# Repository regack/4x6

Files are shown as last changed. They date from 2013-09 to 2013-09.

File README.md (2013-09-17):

4x6
===

4x6 Keypad
v0.1
Based on GH60 Rev B

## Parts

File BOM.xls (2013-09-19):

ref | value | datasheet | footprint | Field1 | Field2 | Field3 | Field4 | Field5 | Field6 | Field7
C1 | 22p | http://www.tme.eu/pl/Document/7da762c1dbaf553c64ad9c40d3603826/mlcc_samsung.pdf |  | http://www.tme.eu/pl/Document/7da762c1dbaf553c64ad9c40d3603826/mlcc_samsung.pdf | Samsung | CL21C220JBANNNC | TME | CL21C220JBANNNC
C2 | 22p | http://www.tme.eu/pl/Document/7da762c1dbaf553c64ad9c40d3603826/mlcc_samsung.pdf |  | http://www.tme.eu/pl/Document/7da762c1dbaf553c64ad9c40d3603826/mlcc_samsung.pdf | Samsung | CL21C220JBANNNC | TME | CL21C220JBANNNC
C3 | 1u | http://www.jm.pl/karty/CCCX7R.pdf |  | http://www.jm.pl/karty/CCCX7R.pdf | Samsung | CL21B105KAFNNNE | TME | CL21B105KAFNNNE
C4 | 100n | http://www.tme.eu/pl/Document/7da762c1dbaf553c64ad9c40d3603826/mlcc_samsung.pdf |  | http://www.tme.eu/pl/Document/7da762c1dbaf553c64ad9c40d3603826/mlcc_samsung.pdf | Samsung | CL21B104KBCNNNC | TME | CL21B104KBCNNNC
C5 | 100n | http://www.tme.eu/pl/Document/7da762c1dbaf553c64ad9c40d3603826/mlcc_samsung.pdf |  | http://www.tme.eu/pl/Document/7da762c1dbaf553c64ad9c40d3603826/mlcc_samsung.pdf | Samsung | CL21B104KBCNNNC | TME | CL21B104KBCNNNC
C6 | 100n | http://www.tme.eu/pl/Document/7da762c1dbaf553c64ad9c40d3603826/mlcc_samsung.pdf |  | http://www.tme.eu/pl/Document/7da762c1dbaf553c64ad9c40d3603826/mlcc_samsung.pdf | Samsung | CL21B104KBCNNNC | TME | CL21B104KBCNNNC
C7 | 100n | http://www.tme.eu/pl/Document/7da762c1dbaf553c64ad9c40d3603826/mlcc_samsung.pdf |  | http://www.tme.eu/pl/Document/7da762c1dbaf553c64ad9c40d3603826/mlcc_samsung.pdf | Samsung | CL21B104KBCNNNC | TME | CL21B104KBCNNNC
C8 | 1u | http://www.tme.eu/pl/Document/7da762c1dbaf553c64ad9c40d3603826/mlcc_samsung.pdf |  | http://www.tme.eu/pl/Document/7da762c1dbaf553c64ad9c40d3603826/mlcc_samsung.pdf | Samsung | CL21B104KBCNNNC | TME | CL21B104KBCNNNC
D1 | 1N4148 |  |  |  | DC Components | CD4148WS(0805C) | TME | 1N4148-0805
D2 | 1N4148 |  |  |  | DC Components | CD4148WS(0805C) | TME | 1N4148-0805
D3 | 1N4148 |  |  |  | DC Components | CD4148WS(0805C) | TME | 1N4148-0805
D4 | 1N4148 |  |  |  | DC Components | CD4148WS(0805C) | TME | 1N4148-0805
D5 | 1N4148 |  |  |  | DC Components | CD4148WS(0805C) | TME | 1N4148-0805
D6 | 1N4148 |  |  |  | DC Components | CD4148WS(0805C) | TME | 1N4148-0805
D7 | 1N4148 |  |  |  | DC Components | CD4148WS(0805C) | TME | 1N4148-0805
D8 | 1N4148 |  |  |  | DC Components | CD4148WS(0805C) | TME | 1N4148-0805
D9 | 1N4148 |  |  |  | DC Components | CD4148WS(0805C) | TME | 1N4148-0805
D10 | 1N4148 |  |  |  | DC Components | CD4148WS(0805C) | TME | 1N4148-0805
D11 | 1N4148 |  |  |  | DC Components | CD4148WS(0805C) | TME | 1N4148-0805
D12 | 1N4148 |  |  |  | DC Components | CD4148WS(0805C) | TME | 1N4148-0805
D13 | 1N4148 |  |  |  | DC Components | CD4148WS(0805C) | TME | 1N4148-0805
D14 | 1N4148 |  |  |  | DC Components | CD4148WS(0805C) | TME | 1N4148-0805
D15 | 1N4148 |  |  |  | DC Components | CD4148WS(0805C) | TME | 1N4148-0805
D16 | 1N4148 |  |  |  | DC Components | CD4148WS(0805C) | TME | 1N4148-0805
D17 | 1N4148 |  |  |  | DC Components | CD4148WS(0805C) | TME | 1N4148-0805
D18 | 1N4148 |  |  |  | DC Components | CD4148WS(0805C) | TME | 1N4148-0805
D19 | 1N4148 |  |  |  | DC Components | CD4148WS(0805C) | TME | 1N4148-0805
D20 | 1N4148 |  |  |  | DC Components | CD4148WS(0805C) | TME | 1N4148-0805
D21 | 1N4148 |  |  |  | DC Components | CD4148WS(0805C) | TME | 1N4148-0805
D22 | 1N4148 |  |  |  | DC Components | CD4148WS(0805C) | TME | 1N4148-0805
D23 | 1N4148 |  |  |  | DC Components | CD4148WS(0805C) | TME | 1N4148-0805
D24 | 1N4148 |  |  |  | DC Components | CD4148WS(0805C) | TME | 1N4148-0805
DC1 | LED
DF1 | LED
DF2 | LED
DF3 | LED
IC1 | ATMEGA32U4 | http://www.atmel.com/dyn/resources/prod_documents/doc7766.pdf | TQFP44 | http://www.atmel.com/dyn/resources/prod_documents/doc7766.pdf | Atmel | ATmega32U4-AU | DigiKey | ATMEGA32U4-AU-ND
J1 | MINI | http://www.tme.eu/pl/Document/af7e127923dc7f74ac659db082bbc882/mx54819.pdf |  | http://www.tme.eu/pl/Document/af7e127923dc7f74ac659db082bbc882/mx54819.pdf | Natconn | U24-05XXX-1 | Alibaba
P1 | MISO
P2 | Vcc
P3 | SCK
P4 | MOSI
P5 | RES
P6 | GND
P200 | GND
P201 | GND
P202 | GND
P203 | GND
P204 | GND
P205 | GND
R1 | 22 | http://www.tme.eu/pl/Document/e5152f6c2c4f933b61676f6de7ae79a8/dcrcw.pdf |  | http://www.tme.eu/pl/Document/e5152f6c2c4f933b61676f6de7ae79a8/dcrcw.pdf | Vishay | CRCW080522R0JNTABC | TME | CRCW080522R0JNTABC
R2 | 22 | http://www.tme.eu/pl/Document/e5152f6c2c4f933b61676f6de7ae79a8/dcrcw.pdf |  | http://www.tme.eu/pl/Document/e5152f6c2c4f933b61676f6de7ae79a8/dcrcw.pdf | Vishay | CRCW080522R0JNTABC | TME | CRCW080522R0JNTABC
R3 | 10k | http://www.tme.eu/pl/Document/e5152f6c2c4f933b61676f6de7ae79a8/dcrcw.pdf |  | http://www.tme.eu/pl/Document/e5152f6c2c4f933b61676f6de7ae79a8/dcrcw.pdf | Vishay | CRCW080510K0JNTABC | TME | CRCW080510K0JNTABC
R4 | 300
R5 | 10k | http://www.tme.eu/pl/Document/e5152f6c2c4f933b61676f6de7ae79a8/dcrcw.pdf |  | http://www.tme.eu/pl/Document/e5152f6c2c4f933b61676f6de7ae79a8/dcrcw.pdf | Vishay | CRCW080510K0JNTABC | TME | CRCW080510K0JNTABC
RF1 | R
RF2 | R
RF3 | R
S0 | DTSM-6 | http://www.jm.pl/karty/DTSJW.pdf | switch-tact-DTSM-6 | http://www.jm.pl/karty/DTSJW.pdf | Ninigi | TACTB-64K-F | TME | TACTB-64K-F
S1 | MX1A
S2 | MX1A
S3 | MX1A
S4 | MX1A
S5 | MX1A
S6 | MX1A
S7 | MX1A
S8 | MX1A
S9 | MX1A
S10 | MX1A
S11 | MX1A
S12 | MX1A
S13 | MX1A
S14 | MX1A
S15 | MX1A
S16 | MX1A
S17 | MX1A
S18 | MX1A
S19 | MX1A
S20 | MX1A
S21 | MX1A
S22 | MX1A
S23 | MX1A
S24 | MX1A
S51 | MX1A
S171 | MX1A
S181 | MX1A
S191 | MX1A
S201 | MX1A
S211 | MX1A
X1 | ASX3F |  |  |  | YIC | 16.00M-SMDXT324 | TME | 16.00M-SMDXT324

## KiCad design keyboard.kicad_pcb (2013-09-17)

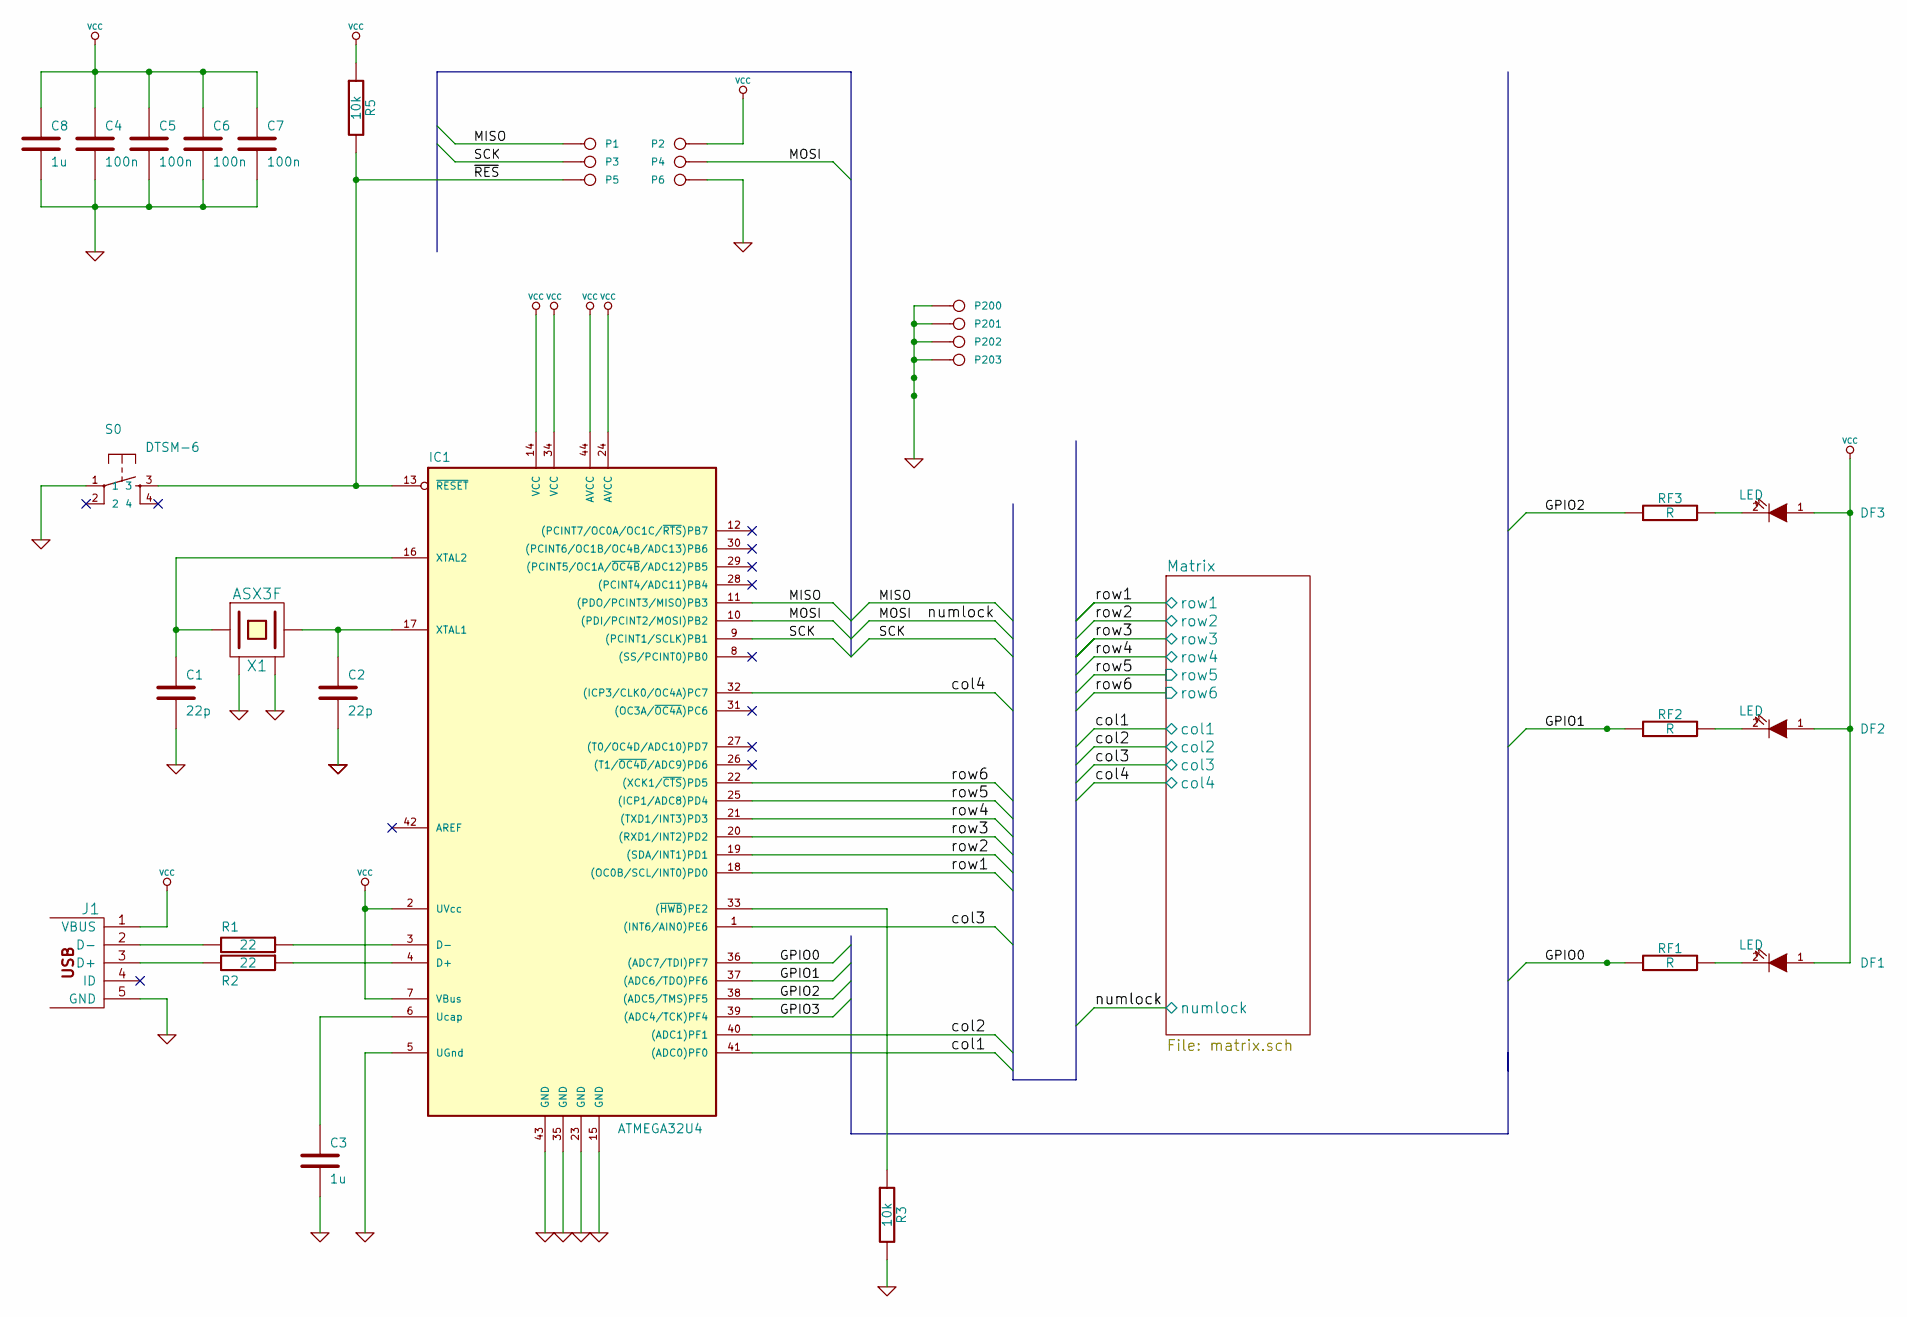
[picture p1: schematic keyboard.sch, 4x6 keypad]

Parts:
C1, C2: 22p
C3, C8: 1u
C4, C5, C6, C7: 100n
DF1, DF2, DF3: LED
IC1: ATMEGA32U4; TQFP44
J1: MINI
P1: MISO
P2: Vcc
P3: SCK
P4: MOSI
P5: RES
P6, P200, P201, P202, P203: GND
R1, R2: 22
R3, R5: 10k
RF1, RF2, RF3: R
S0: DTSM-6; switch-tact-DTSM-6
X1: ASX3F

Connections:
/GPIO0: IC1.36 ((ADC7/TDI)PF7), RF1.1
/GPIO1: IC1.37 ((ADC6/TDO)PF6), RF2.1
/GPIO2: IC1.38 ((ADC5/TMS)PF5), RF3.1
/MISO: IC1.11 ((PDO/PCINT3/MISO)PB3), P1.1
/Matrix/col1: IC1.41 ((ADC0)PF0); also elsewhere on the board
/Matrix/col2: IC1.40 ((ADC1)PF1); also elsewhere on the board
/Matrix/col3: IC1.1 ((INT6/AIN0)PE6); also elsewhere on the board
/Matrix/col4: IC1.32 ((ICP3/CLK0/OC4A)PC7); also elsewhere on the board
/Matrix/numlock: IC1.10 ((PDI/PCINT2/MOSI)PB2), P4.1; also elsewhere on the board
/Matrix/row1: IC1.18 ((OC0B/SCL/INT0)PD0); also elsewhere on the board
/Matrix/row2: IC1.19 ((SDA/INT1)PD1); also elsewhere on the board
/Matrix/row3: IC1.20 ((RXD1/INT2)PD2); also elsewhere on the board
/Matrix/row4: IC1.21 ((TXD1/INT3)PD3); also elsewhere on the board
/Matrix/row5: IC1.25 ((ICP1/ADC8)PD4); also elsewhere on the board
/Matrix/row6: IC1.22 ((XCK1/~CTS~)PD5); also elsewhere on the board
/SCK: IC1.9 ((PCINT1/SCLK)PB1), P3.1
/~RES~: IC1.13 (~RESET~), P5.1, R5.2, S0.3
GND: C1.2, C2.2, C3.2, C4.2, C5.2, C6.2, C7.2, C8.2, IC1.5 (UGnd), IC1.15 (GND), IC1.23 (GND), IC1.35 (GND), IC1.43 (GND), J1.5 (GND), P6.1, P200.1, P201.1, P202.1, P203.1, R3.2, S0.1, X1.2 (GND), X1.4 (GND)
unnamed: C1.1, IC1.16 (XTAL2), X1.1
unnamed: C2.1, IC1.17 (XTAL1), X1.3 (2)
unnamed: J1.2 (D-), R1.2
unnamed: J1.3 (D+), R2.2
unnamed: IC1.3 (D-), R1.1
unnamed: C3.1, IC1.6 (Ucap)
unnamed: IC1.4 (D+), R2.1
unnamed: IC1.33 ((~HWB~)PE2), R3.1
unnamed: DF3.2 (K), RF3.2
unnamed: DF1.2 (K), RF1.2
unnamed: DF2.2 (K), RF2.2
VCC: C4.1, C5.1, C6.1, C7.1, C8.1, DF1.1 (A), DF2.1 (A), DF3.1 (A), IC1.2 (UVcc), IC1.7 (VBus), IC1.14 (VCC), IC1.24 (AVCC), IC1.34 (VCC), IC1.44 (AVCC), J1.1 (VBUS), P2.1, R5.1; also elsewhere on the board

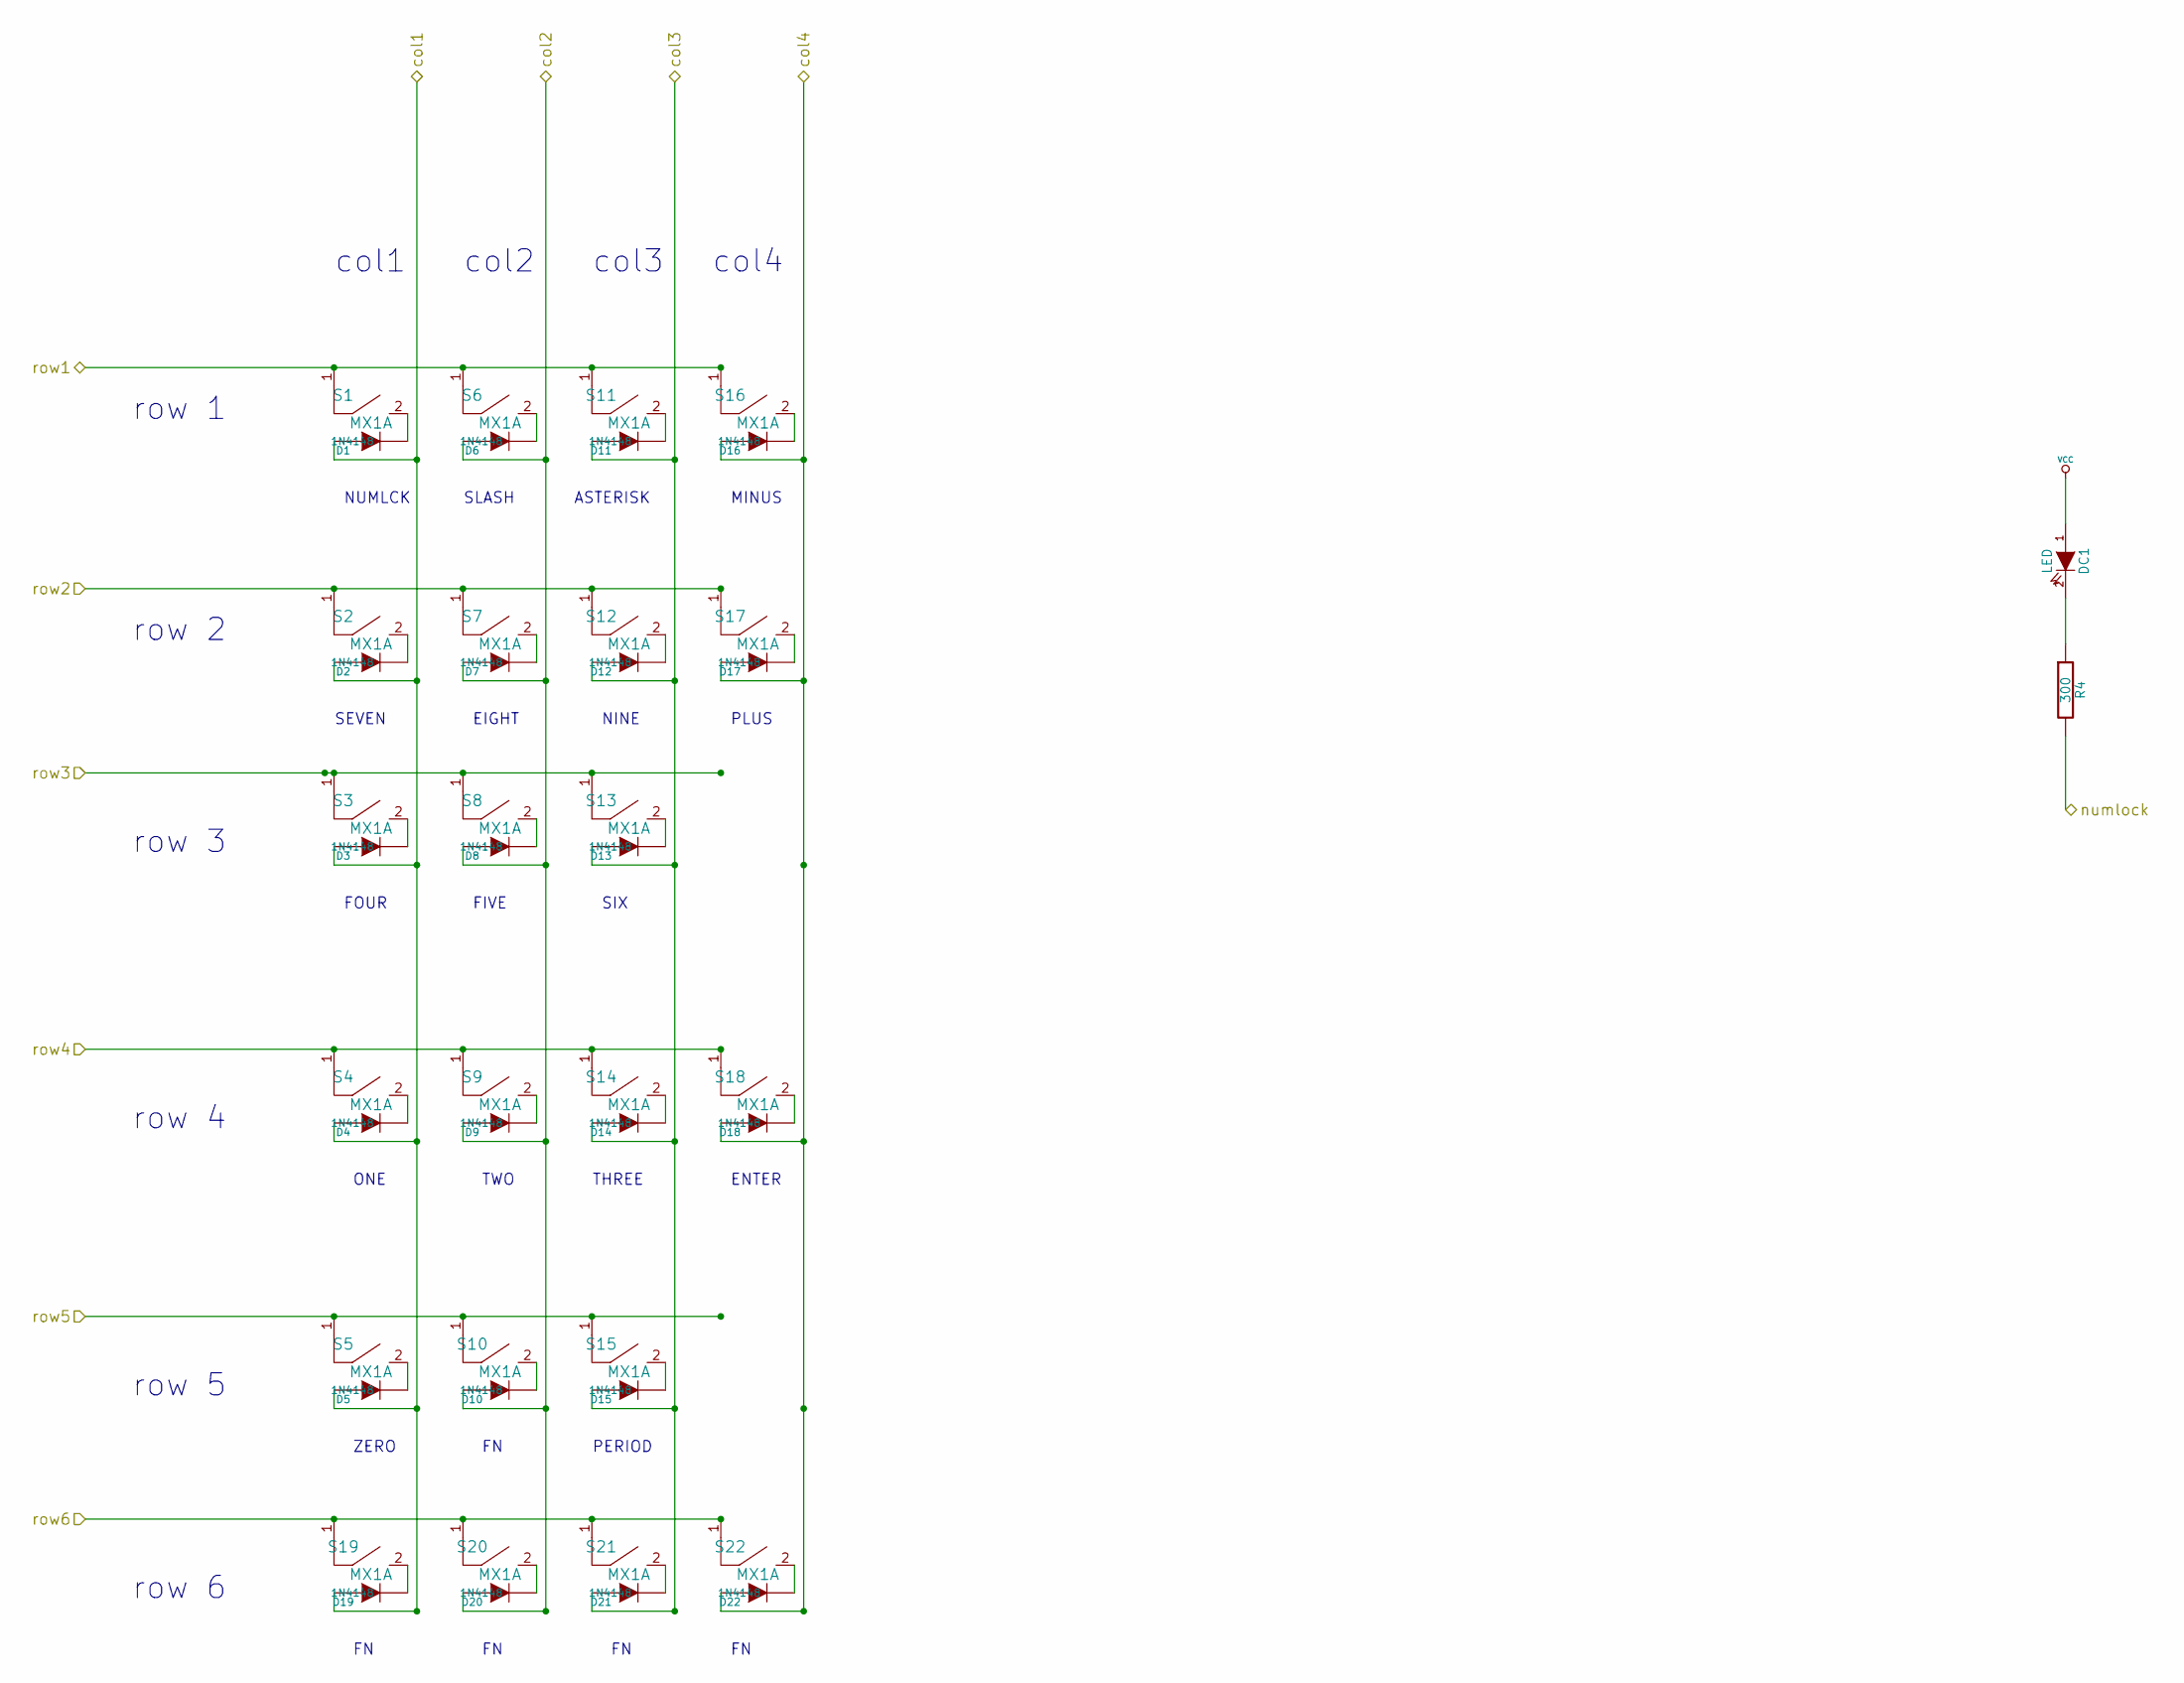
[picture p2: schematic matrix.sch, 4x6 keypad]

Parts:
D1, D2, D3, D4, D5, D6, D7, D8, D9, D10, D11, D12, D13, D14, D15, D16, D17, D18, D19, D20, D21, D22: 1N4148
DC1: LED
R4: 300
S1, S2, S3, S4, S5, S6, S7, S8, S9, S10, S11, S12, S13, S14, S15, S16, S17, S18, S19, S20, S21, S22: MX1A

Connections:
/Matrix/col1: D1.1 (A), D2.1 (A), D3.1 (A), D4.1 (A), D5.1 (A), D19.1 (A); also elsewhere on the board
/Matrix/col2: D6.1 (A), D7.1 (A), D8.1 (A), D9.1 (A), D10.1 (A), D20.1 (A); also elsewhere on the board
/Matrix/col3: D11.1 (A), D12.1 (A), D13.1 (A), D14.1 (A), D15.1 (A), D21.1 (A); also elsewhere on the board
/Matrix/col4: D16.1 (A), D17.1 (A), D18.1 (A), D22.1 (A); also elsewhere on the board
/Matrix/numlock: R4.2; also elsewhere on the board
/Matrix/row1: S1.1, S6.1, S11.1, S16.1; also elsewhere on the board
/Matrix/row2: S2.1, S7.1, S12.1, S17.1; also elsewhere on the board
/Matrix/row3: S3.1, S8.1, S13.1; also elsewhere on the board
/Matrix/row4: S4.1, S9.1, S14.1, S18.1; also elsewhere on the board
/Matrix/row5: S5.1, S10.1, S15.1; also elsewhere on the board
/Matrix/row6: S19.1, S20.1, S21.1, S22.1; also elsewhere on the board
unnamed: D4.2 (K), S4.2
unnamed: D18.2 (K), S18.2
unnamed: D3.2 (K), S3.2
unnamed: D5.2 (K), S5.2
unnamed: D10.2 (K), S10.2
unnamed: D15.2 (K), S15.2
unnamed: D16.2 (K), S16.2
unnamed: D17.2 (K), S17.2
unnamed: D1.2 (K), S1.2
unnamed: D20.2 (K), S20.2
unnamed: D21.2 (K), S21.2
unnamed: D19.2 (K), S19.2
unnamed: D22.2 (K), S22.2
unnamed: DC1.2 (K), R4.1
unnamed: D6.2 (K), S6.2
unnamed: D11.2 (K), S11.2
unnamed: D2.2 (K), S2.2
unnamed: D7.2 (K), S7.2
unnamed: D12.2 (K), S12.2
unnamed: D8.2 (K), S8.2
unnamed: D13.2 (K), S13.2
unnamed: D9.2 (K), S9.2
unnamed: D14.2 (K), S14.2
VCC: DC1.1 (A); also elsewhere on the board

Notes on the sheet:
row 1
row 2
row 3
row 4
col1
col2
col3
col4
NUMLCK
SEVEN
SLASH
ASTERISK
MINUS
FOUR
EIGHT
NINE
PLUS
ONE
TWO
THREE
FIVE
SIX
ENTER
row 5
ZERO
PERIOD
row 6

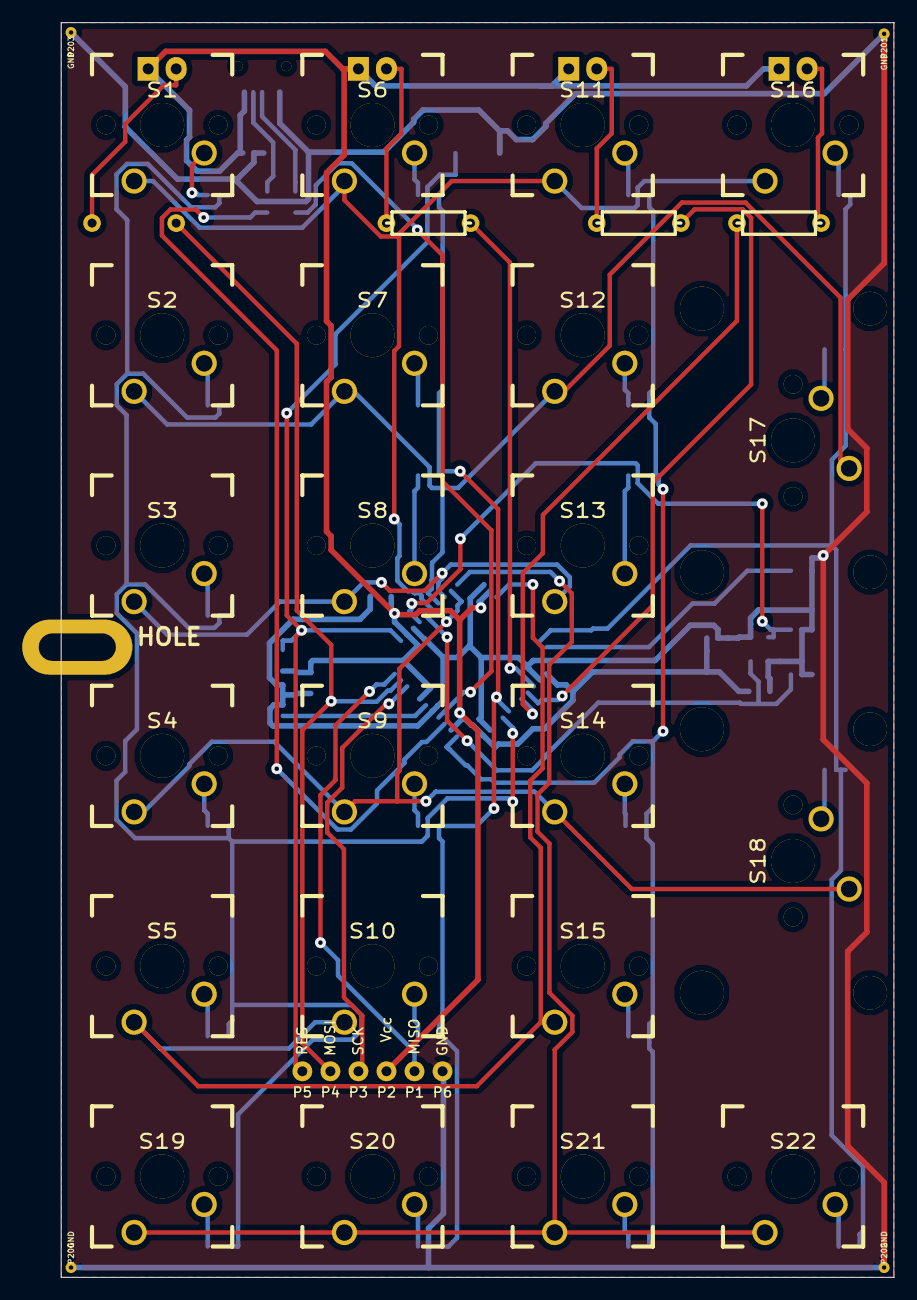
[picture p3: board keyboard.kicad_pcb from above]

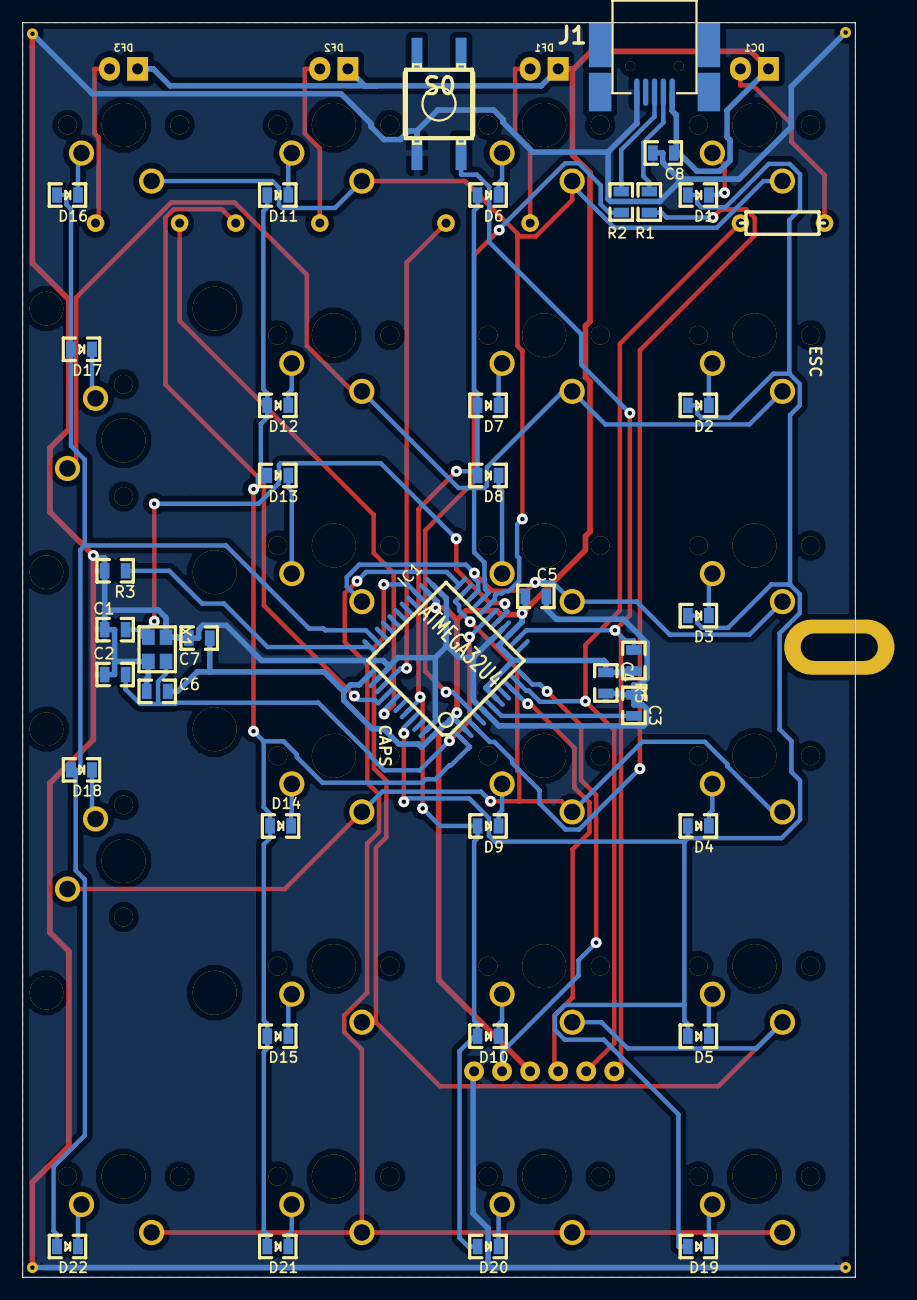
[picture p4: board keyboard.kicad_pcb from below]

Board: 2 copper layers, 75.4 x 113.7 mm, 79 parts (39 on the bottom side), 53 nets.

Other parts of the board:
H2: HOLE; PKRHSL

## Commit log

2013-09-17 Initial Revision
    [keyboard-B_Mask.gbs, keyboard-B_SilkS.gbo, keyboard-Back.gbl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]
2013-09-18 parts list
    [keyboard.csv]
2013-09-19 bill of materials
    [BOM.xls]
